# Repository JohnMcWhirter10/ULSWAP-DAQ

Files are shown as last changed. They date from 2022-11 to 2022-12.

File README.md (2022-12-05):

# Ultra Low Size Weight and Power Data Acquisition Unit C Project and Altium Files

The contents of this repository include the altium files for each subsystem in
appropriately named directories. The use of this repository is solely for Texas A&M 
University and Sandia National Laboratories.

## Authors

- John McWhirter
- Andrew Bainbridge
- Robert Brown

## Table of Contents

- Power Module Subsystem Altium Files
- Signal Conditioning Subsystem Altium Files
- Processor and Interface Altium Files
- Initial C Project for the PIC32 (Recommendation: Open in MPLAB X IDE)

## Documentation

The Documentation for the C Project can be found by following this path:

UL-SWaP-DaQ-1.0 > doxygen > html > index.html

To open in the browser, one must download the UL-SWaP-DaQ-1.0 Directory to 
their local machine and follow the path above to the index.html file.

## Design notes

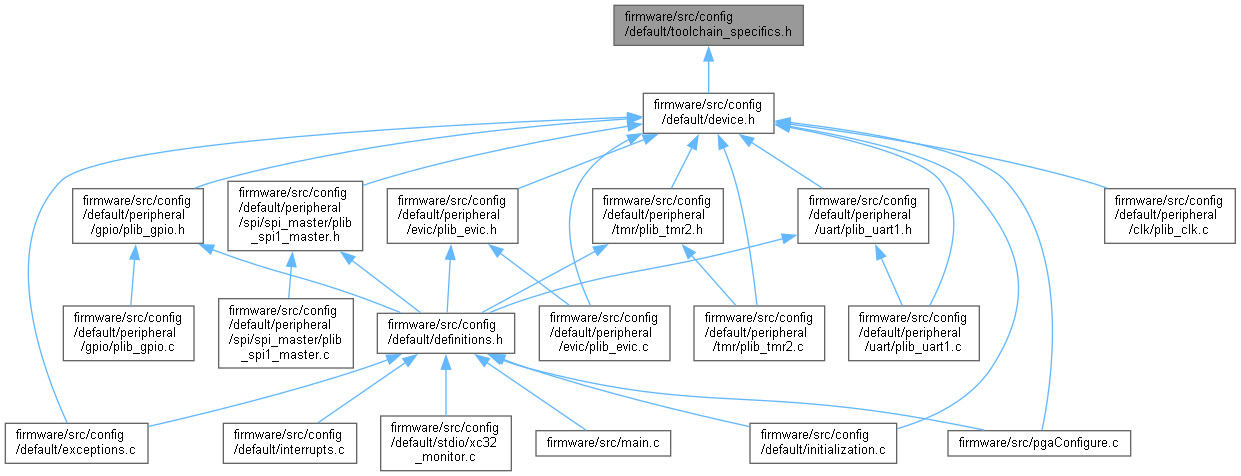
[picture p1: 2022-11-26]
ULSWAP-DAQ-1.0/doxygen/html/toolchain__specifics_8h__dep__incl.png

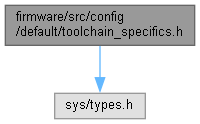
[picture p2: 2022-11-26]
ULSWAP-DAQ-1.0/doxygen/html/toolchain__specifics_8h__incl.png

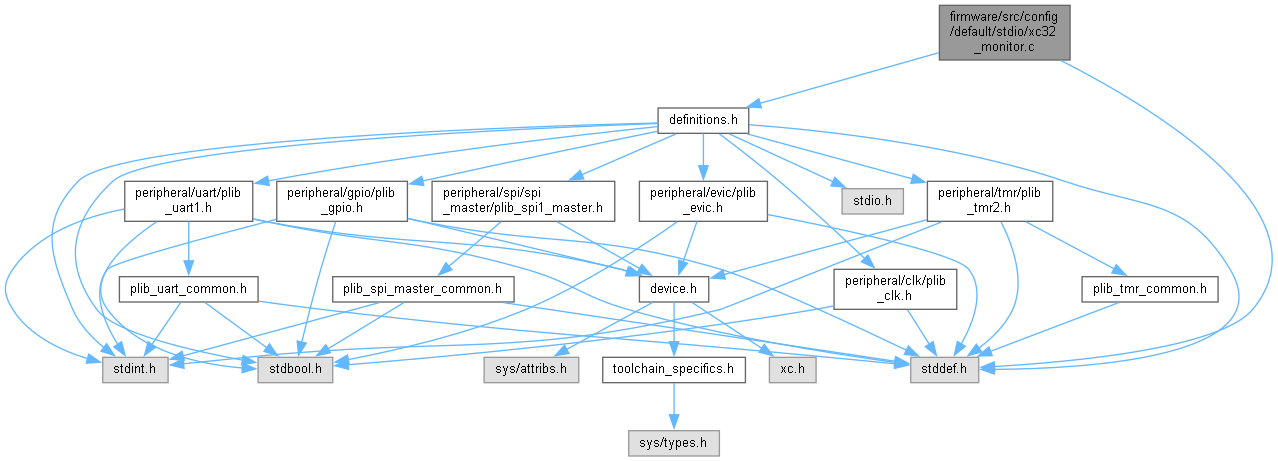
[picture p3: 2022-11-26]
ULSWAP-DAQ-1.0/doxygen/html/xc32__monitor_8c__incl.png

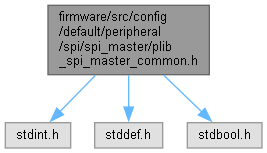
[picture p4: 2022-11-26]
ULSWAP-DAQ-1.0/doxygen/html/plib__spi__master__common_8h__incl.png

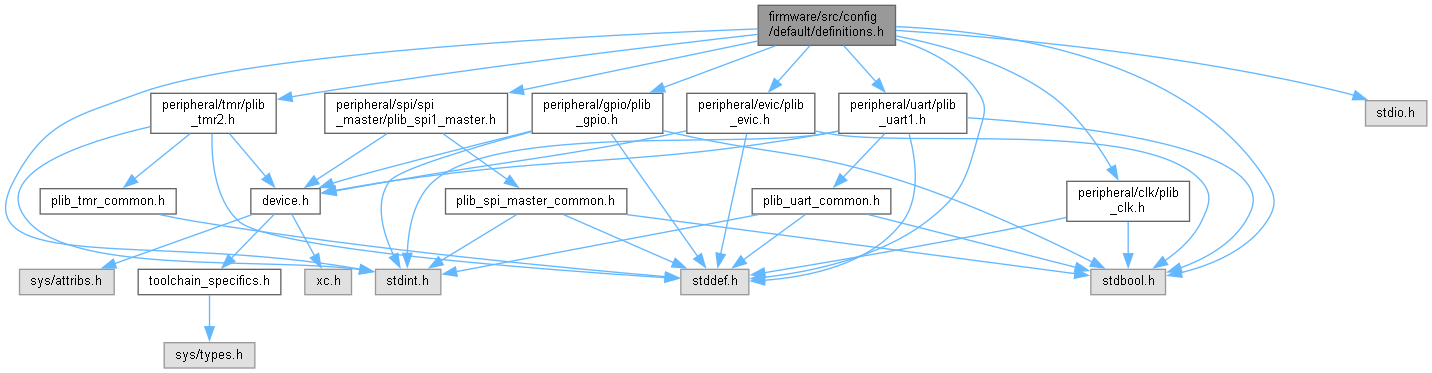
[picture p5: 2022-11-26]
ULSWAP-DAQ-1.0/doxygen/html/definitions_8h__incl.png

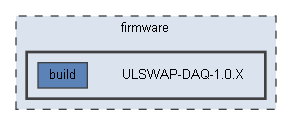
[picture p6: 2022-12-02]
ULSWAP-DAQ-1.0/doxygen/html/dir_9889642713a72f8b6f39e76810b143b5_dep.png

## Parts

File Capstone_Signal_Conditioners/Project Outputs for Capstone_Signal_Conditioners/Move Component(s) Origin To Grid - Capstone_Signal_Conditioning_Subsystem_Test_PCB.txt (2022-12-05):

Move Component(s) Origin to Grid
Filename     : C:\Users\Public\Documents\Altium\Capstone_Signal_Conditioners\Capstone_Signal_Conditioning_Subsystem_Test_PCB.PcbDoc
Date         : 11/2/2022
Time         : 10:20:12 AM
Time Elapsed : 00:00:00

    SOIC Component Designator6-Comment (40.64mm,61.849mm) on Top Layer - Component origin is already ON grid. - Component pads are OFF grid. No action taken.
    SOIC Component Designator5-Comment (40.95mm,68.893mm) on Top Layer - Component pads are OFF grid. No action taken.
    Component Designator2-Comment (25.656mm,65.752mm) on Top Layer - Component pads are OFF grid. No action taken.
count : 3

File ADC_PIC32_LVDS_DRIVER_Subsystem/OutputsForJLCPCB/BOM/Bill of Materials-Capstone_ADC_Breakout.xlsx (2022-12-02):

Comment | Designator | Footprint
C0805C476M9PACTU | C1 | FP-C0805C476M9PACTU-MFG
GRM155R71C104KA88D | C2, C3 | FP-GRM15-MFG
GRM188R71A225KE15D | C4 | FP-GRM188-0_1-e0_2_0_5-MFG
GRM188R60J106ME47D | C5 | FP-GRM188-0_1-e0_2_0_55-IPC_A
SSQ-108-01-T-S | J1, J2 | SMTC-SSQ-108-01-X-S
LTC2373CUH-16#PBF | U1 | LTC_2373_Footprint

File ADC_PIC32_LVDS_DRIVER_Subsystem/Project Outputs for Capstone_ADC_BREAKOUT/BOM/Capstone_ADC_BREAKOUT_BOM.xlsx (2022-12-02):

Designator | Description | Quantity | Comment | Footprint | LibRef
C1 | CAP CER 47UF 6.3V X5R 0805 | 1 | C0805C476M9PACTU | FP-C0805C476M9PACTU-MFG | CMP-2007-01008-2
C2, C3 | CAP CER 0.1UF 16V X7R 0402 | 2 | GRM155R71C104KA88D | FP-GRM15-MFG | CMP-2100-03641-2
C4 | Chip Multilayer Ceramic Capacitors for General Purpose, 0603, 2.2uF, X7R, 15%, 10%, 10V | 1 | GRM188R71A225KE15D | FP-GRM188-0_1-e0_2_0_5-MFG | CMP-2006-02836-2
C5 | Chip Multilayer Ceramic Capacitors for General Purpose, 0603, 10uF, X5R, 15%, 20%, 6.3V | 1 | GRM188R60J106ME47D | FP-GRM188-0_1-e0_2_0_55-IPC_A | CMP-2006-02792-2
J1, J2 | SQ Post Socket, Through-hole, Vertical, -55 to 105 degC, 2.54 mm Pitch, 8-Pin, Female, RoHS | 2 | SSQ-108-01-T-S | SMTC-SSQ-108-01-X-S | CMP-1023-00293-1
U1 |  | 1 | LTC2373CUH-16#PBF | LTC_2373_Footprint | LTC2373CUH-16#PBF

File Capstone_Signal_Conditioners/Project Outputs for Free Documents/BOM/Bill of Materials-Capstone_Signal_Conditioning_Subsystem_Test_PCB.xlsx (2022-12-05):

Comment | Designator | Footprint
LTC6362HMS8#PBF | AmpA, AmpB | LT-MS8-8_L
4-644456-0 | B1 | FP-4-644456-0-MFG
GRM3195C1H163JA01D | C1, C2 | FP-GRM319-0_15-IPC_A
CBR04C108B5GAC | C1A, C1B | FP-CBR04C-MFG
CC0603KRX7R9BB392 | C2A, C2B, C3A, C3B, C4A, C4B | FP-CC0603-DA-MFG
GRM155R71C104KA88D | Cp1-, Cp1+, Cp3-, Cp3+ | FP-GRM15-MFG
C2012JB1A685K060AC | Cp2-, Cp2+, Cp4-, Cp4+ | FP-C2012-060-0_2-IPC_A
NPTC102KFMS-RC | J1, J2 | FP-NPTC102KFMS-RC-0
THS7002CPWP | PGA1 | PWP0028E_M
AC0402JR-0750RL | R1, R2 | FP-AC0402-IPC_C
ERJ-6ENF1241V | R1A, R1B, RgA, RgB | RESC2013X70X40LL20T20
RC0805FR-071KL | R2A, R2B, RfA, RfB | RESC2013X60X35ML10T20
RC0402FR-0735R7L | RoA-, RoA+, RoB-, RoB+ | RESC1005X40X25ML05T10

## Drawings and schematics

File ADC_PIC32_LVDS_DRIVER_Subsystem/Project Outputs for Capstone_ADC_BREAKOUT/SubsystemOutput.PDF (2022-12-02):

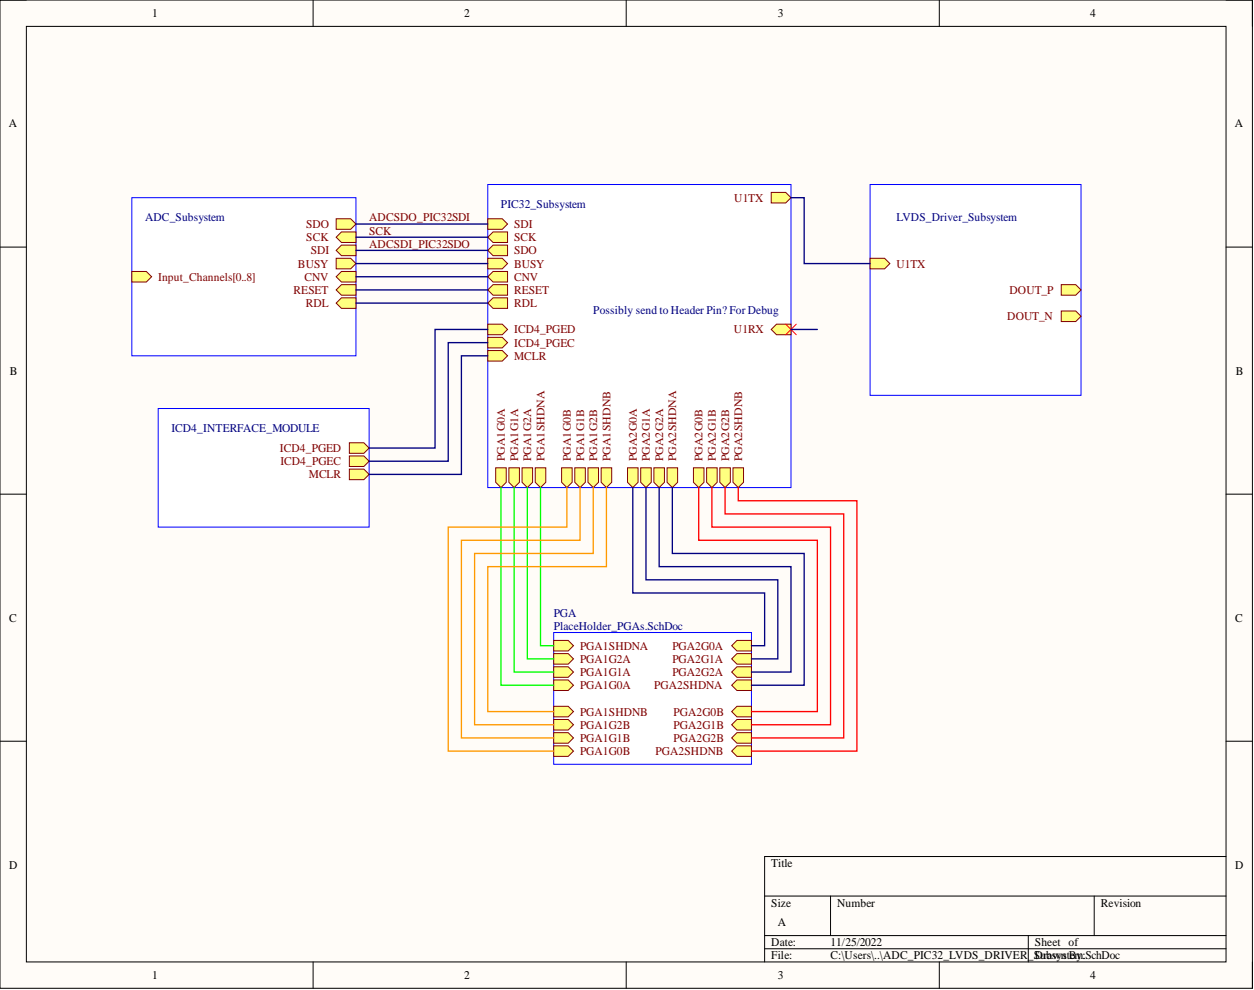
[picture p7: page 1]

Possibly send to Header Pin? For Debug

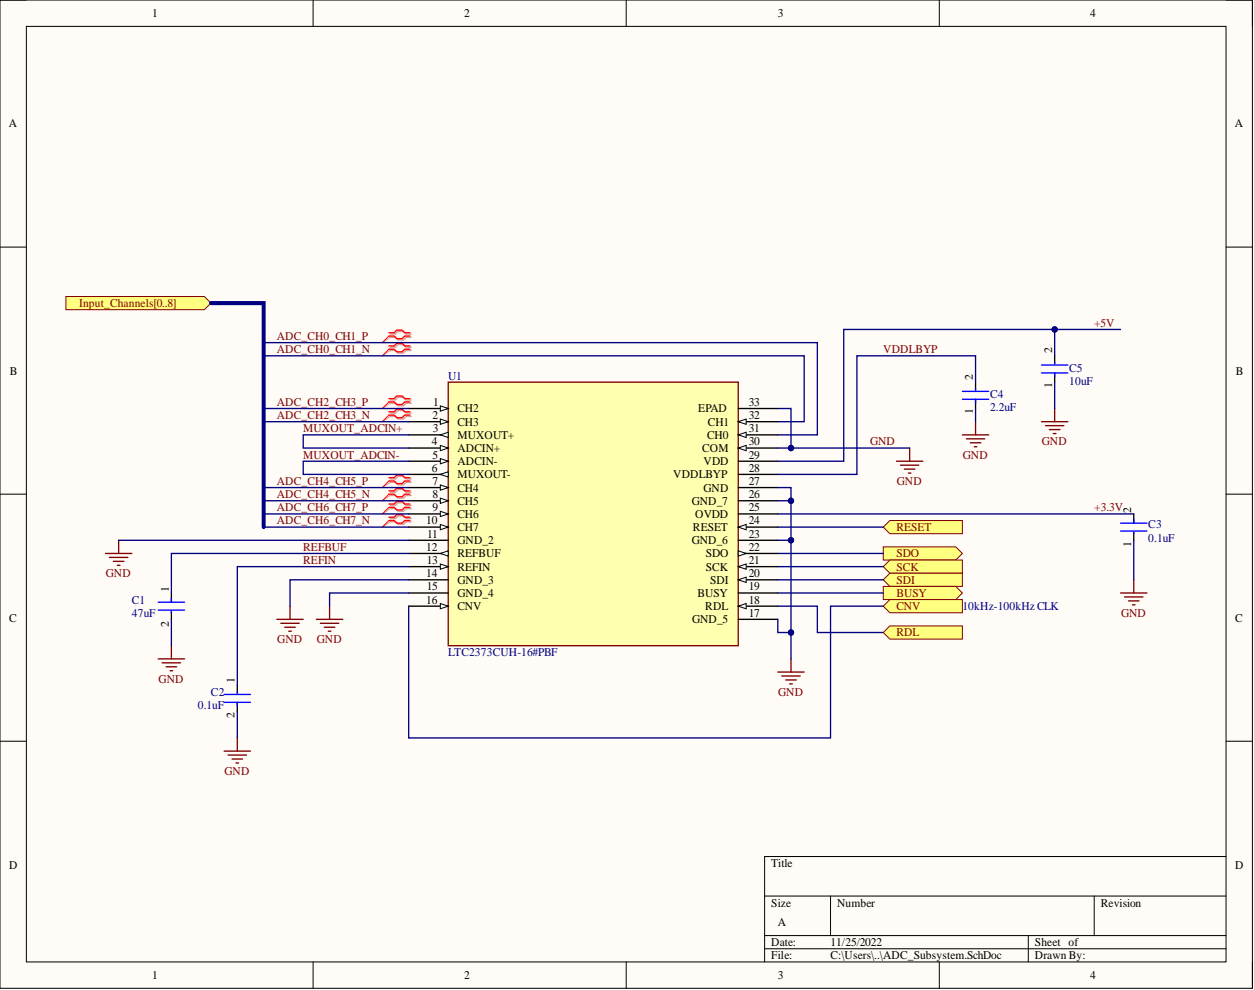
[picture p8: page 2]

MU X O U T _ A D C IN + 3 | CH MU X O U T + 0 | 3 1
A | | | A DCIN + M A DCIN -V D D MU X O U T-V D D LBY P CH 4 G N D CH 5 G N D _ 7 CH 6 O V D D RESE CH 7 T G N D _ 2 G N D _ 6 REFBU F O SCK REFI N SD G N D _ 3 I BU G N D _4 S Y CN V L | 3 0

A DC_CH 4 _ C H 5 _N 8 | | 2 6
A DC_CH 6 _ C H 7 _P 9 | | 2 5
A DC_CH 6 _ C H 7 _N 1 0 | | 2 4

REFBU F 1 | | 2 2
REFI N | 1 3 | | 2 1

1 4 | | 2 0
1 5 | | 1 9

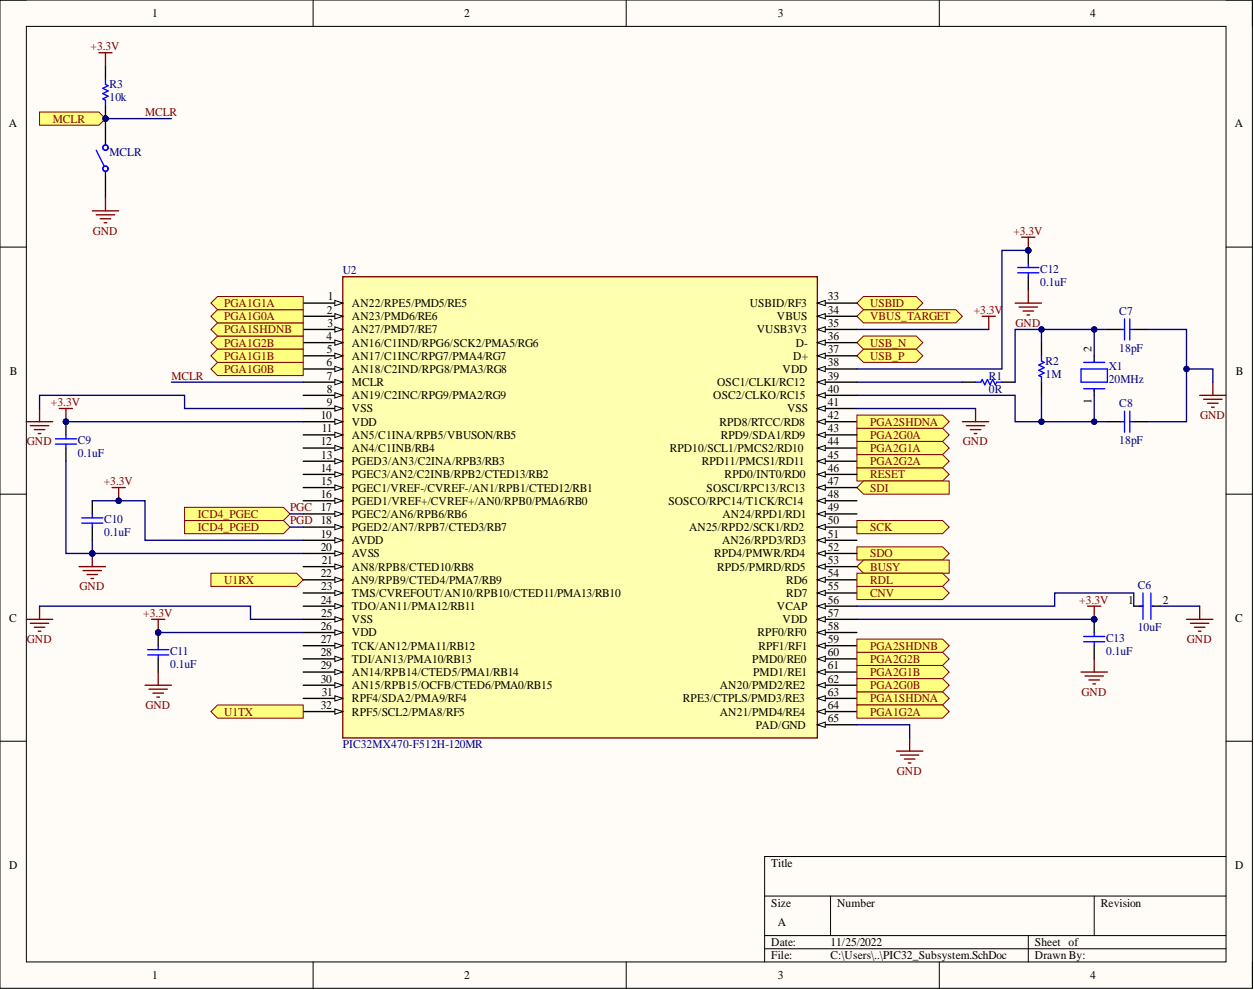
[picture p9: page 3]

1 0 | 4 2
1 1 | 4 3

5 6 | CN V +3.3 V 1
5 7

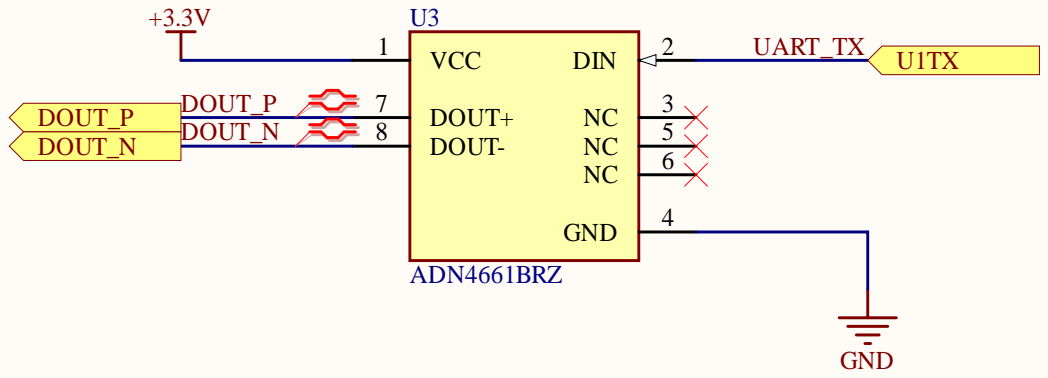
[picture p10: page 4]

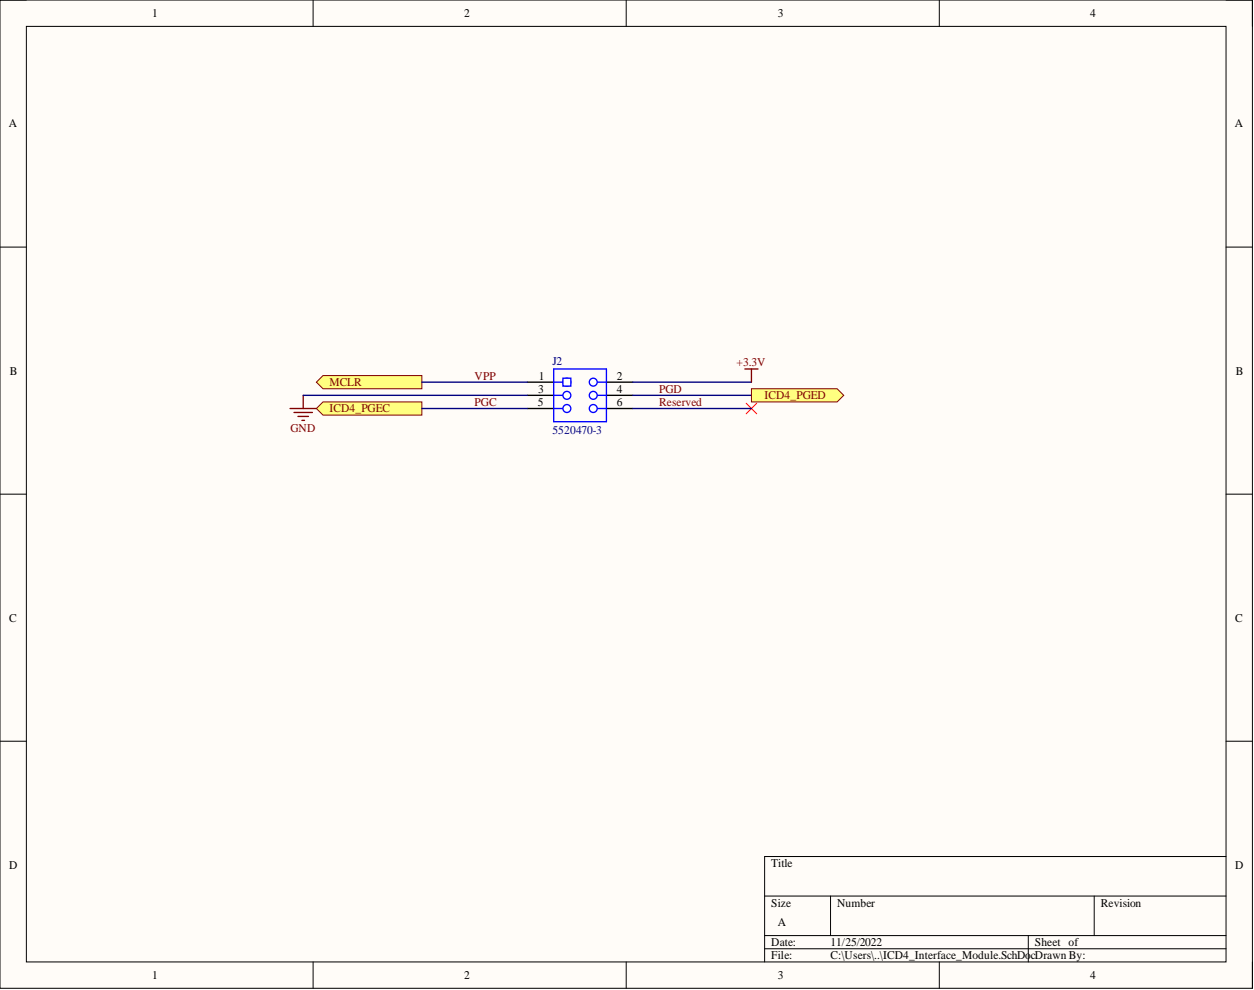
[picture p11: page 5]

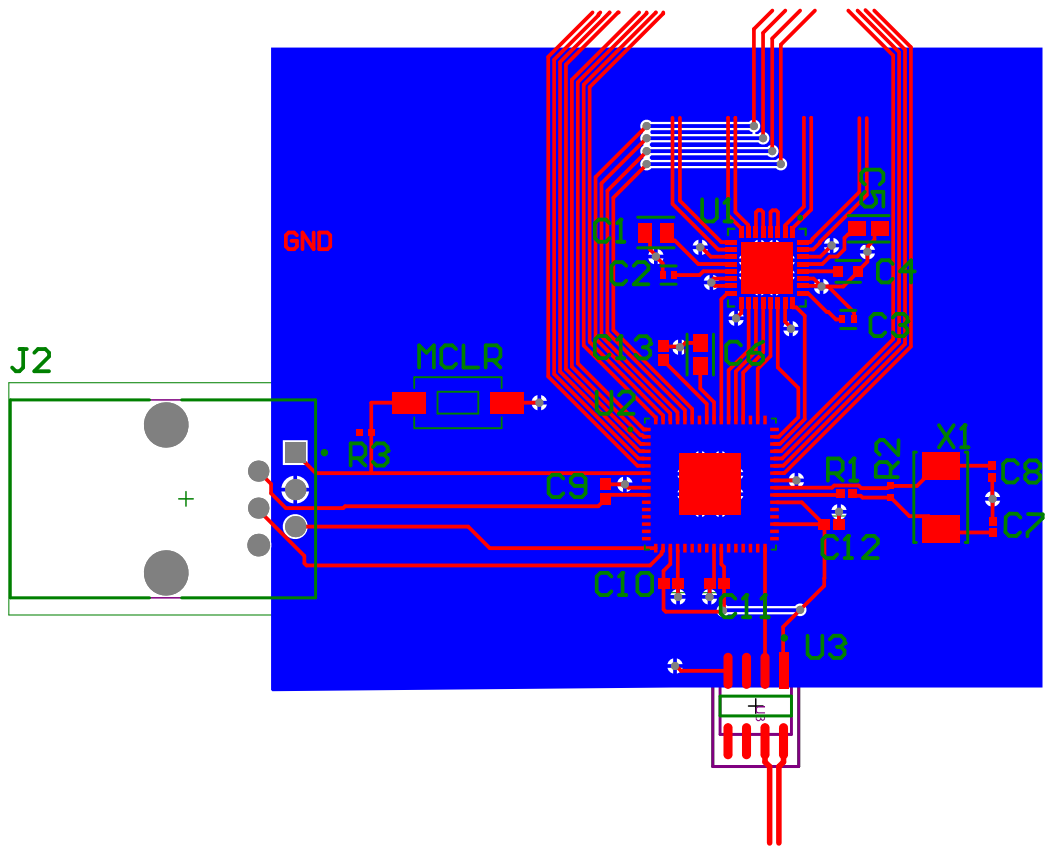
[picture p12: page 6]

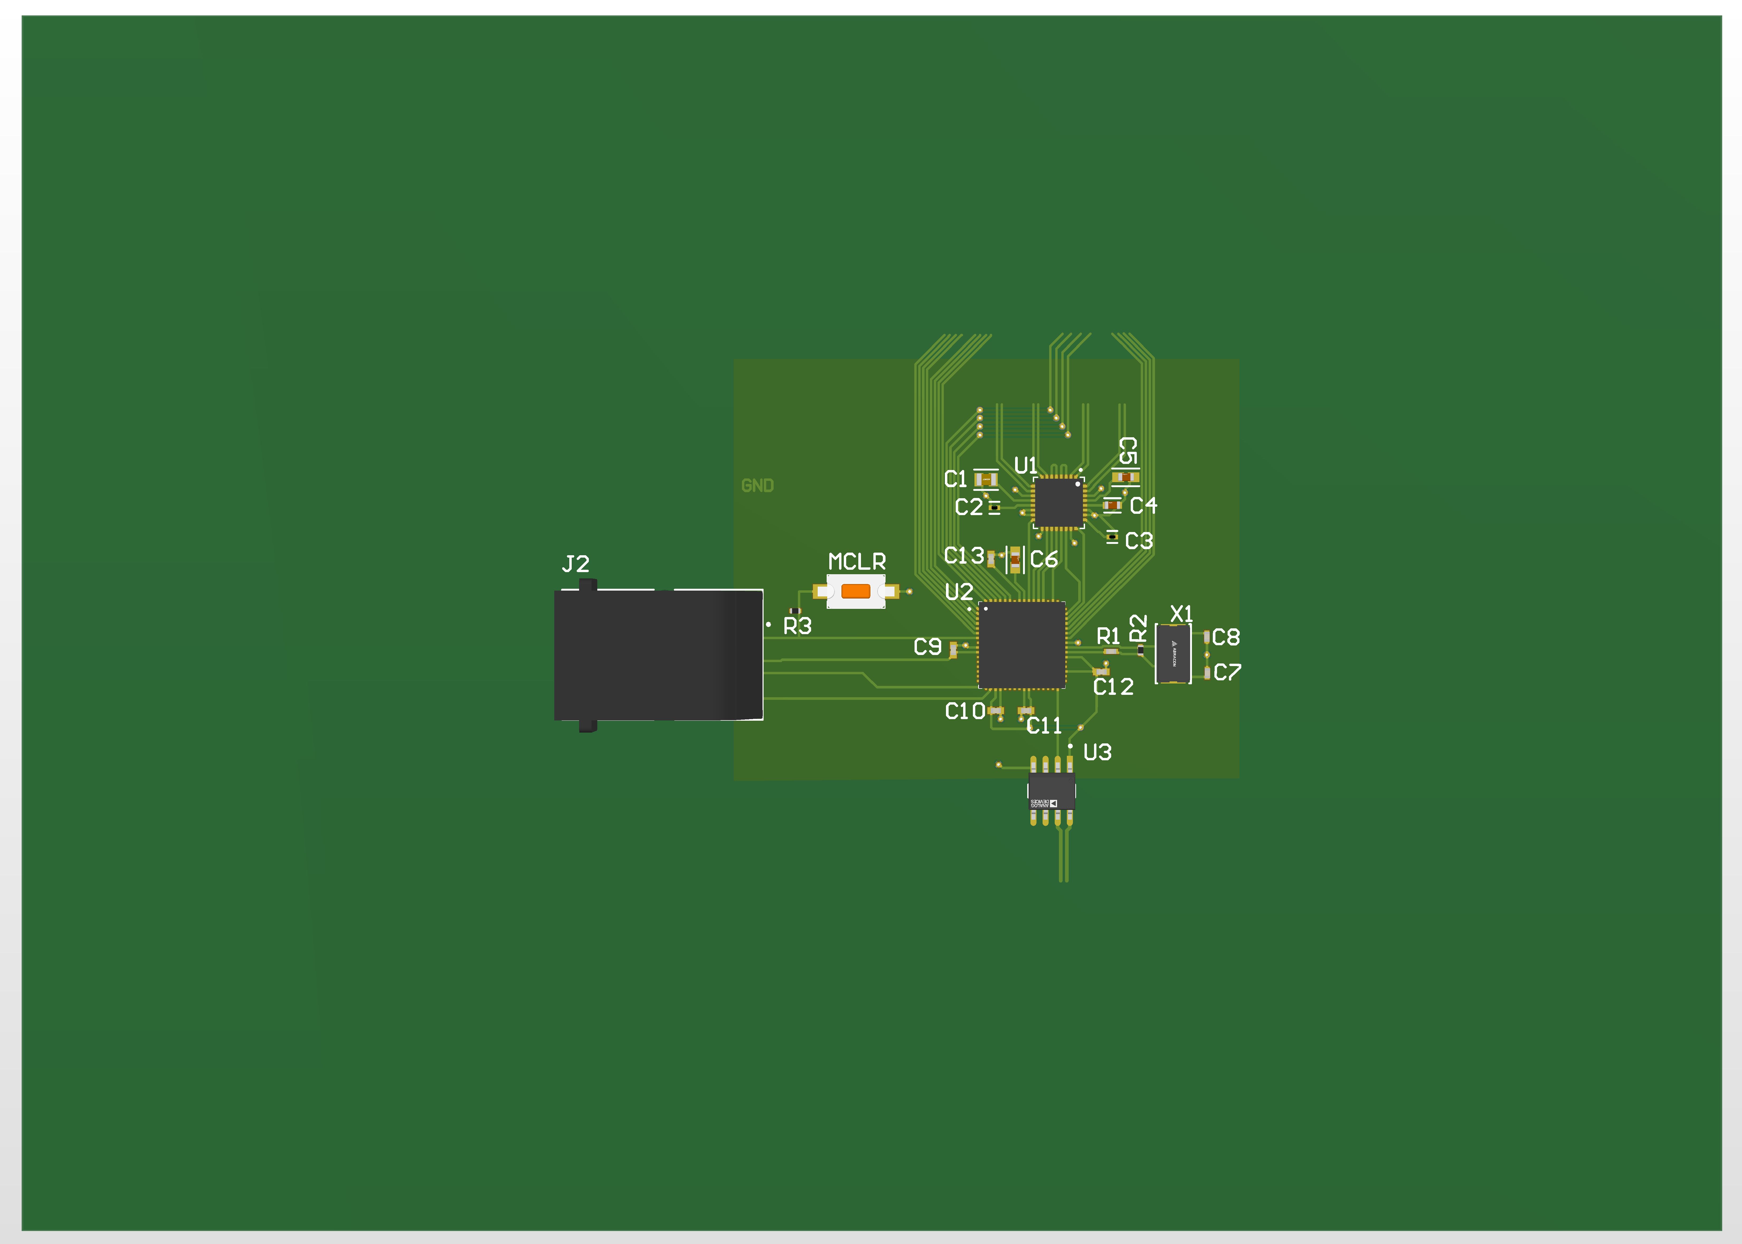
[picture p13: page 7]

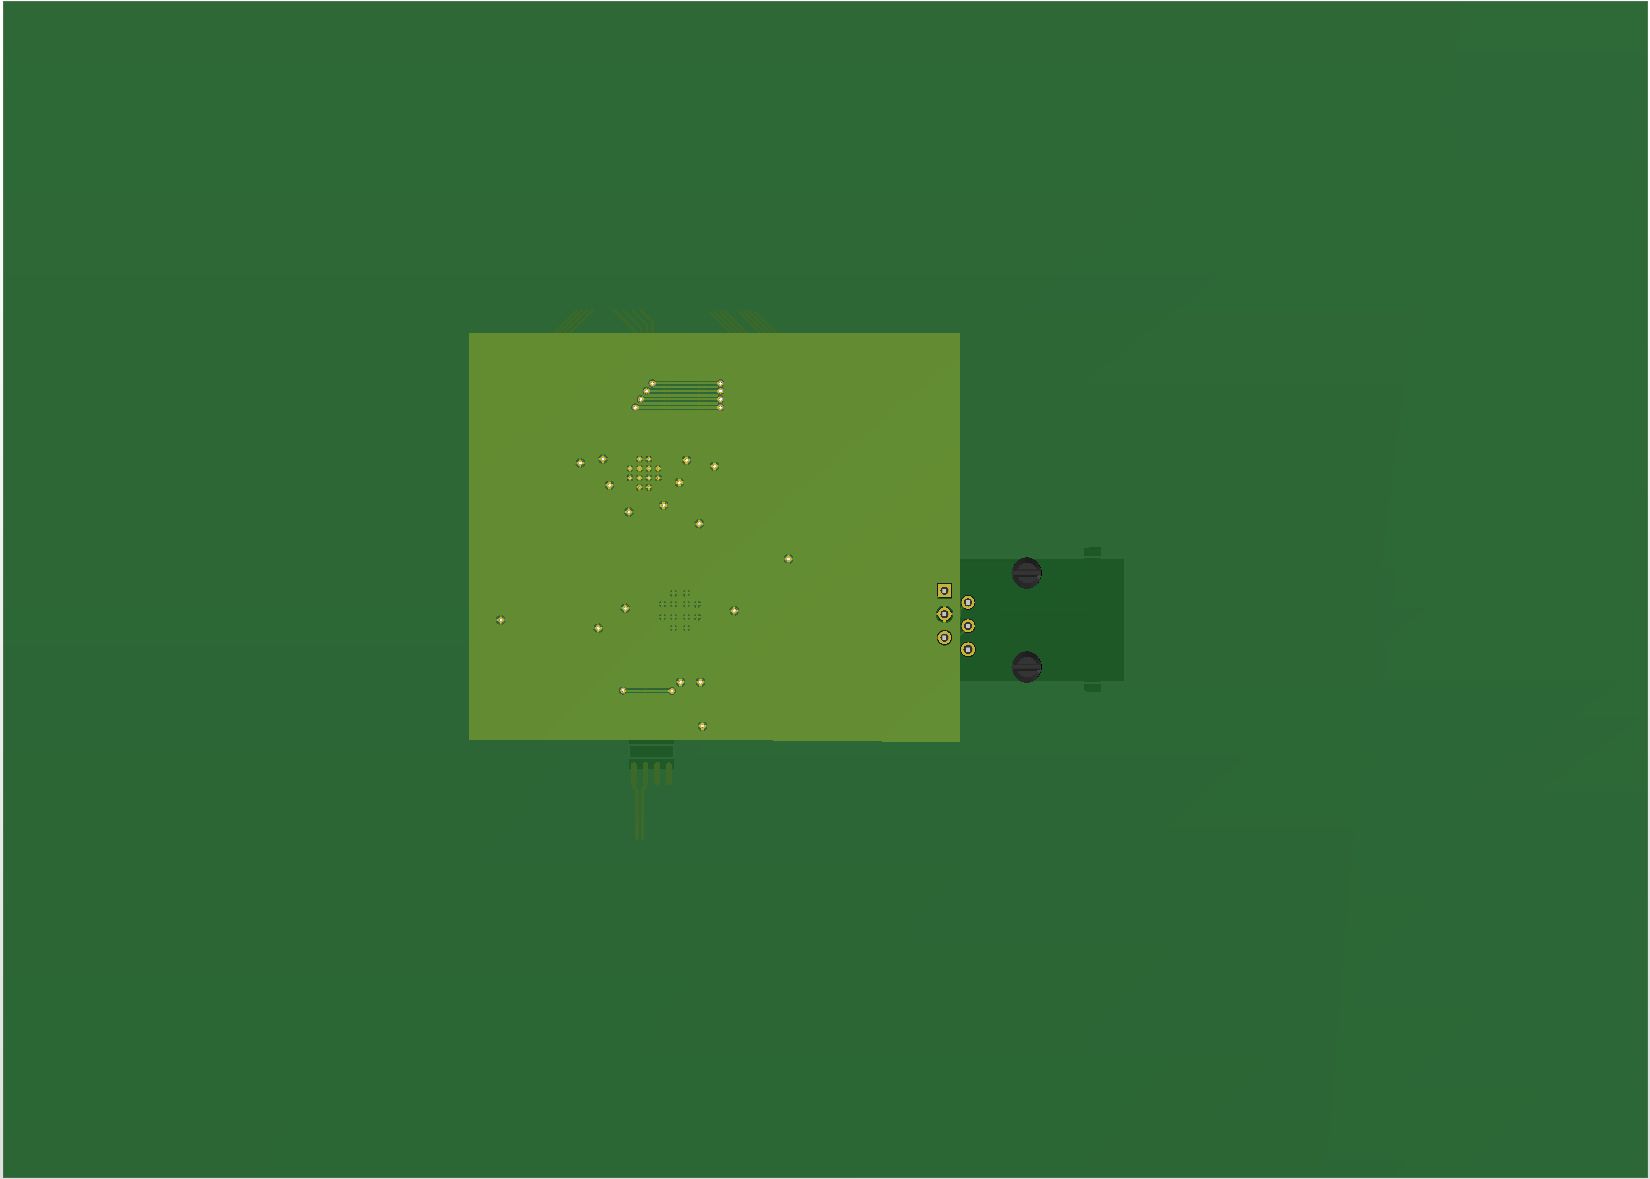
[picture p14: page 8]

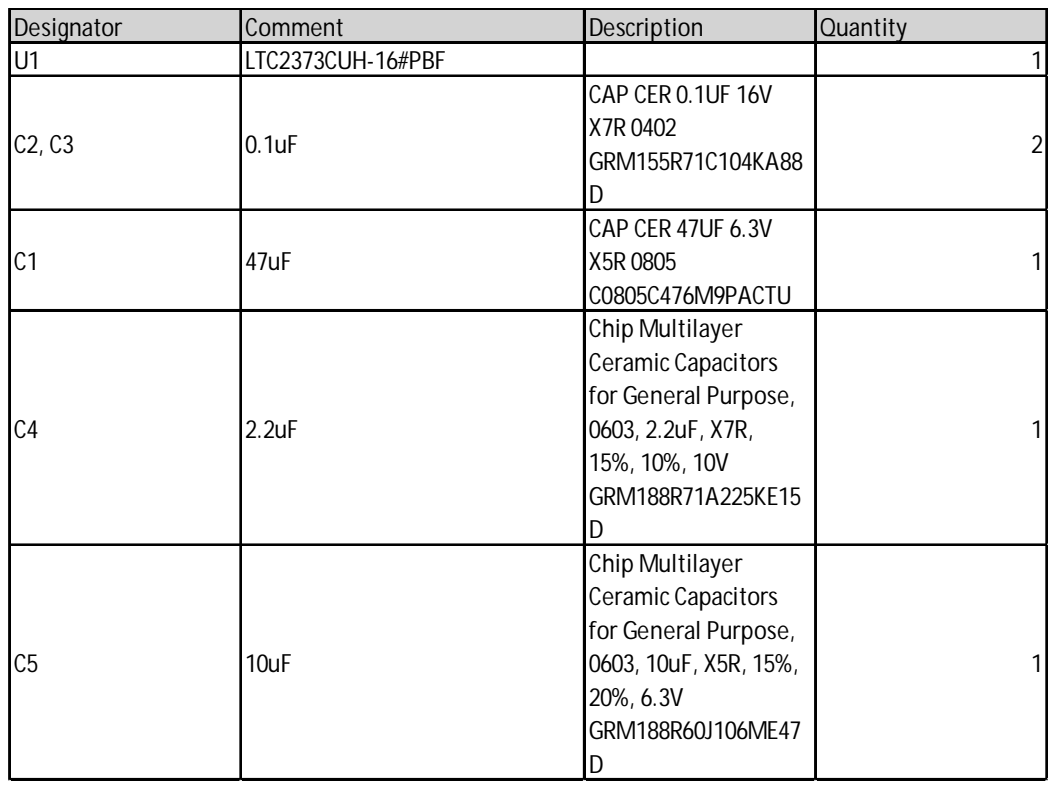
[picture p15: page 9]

Designator | Comment | Description | Quantity
U1 | LTC2373CUH-16#PBF | | 1
C2, C3 | 0.1uF | CAP CER 0.1UF 16V X7R 0402 GRM155R71C104KA88 D | 2

C1 | 47uF | CAP CER 47UF 6.3V X5R 0805 C0805C476M9PACTU | 1

C4 | 2.2uF | Chip Multilayer Ceramic Capacitors for General Purpose, 0603, 2.2uF, X7R, 15%, 10%, 10V GRM188R71A225KE15 D | 1

C5 | 10uF | Chip Multilayer Ceramic Capacitors for General Purpose, 0603, 10uF, X5R, 15%, 20%, 6.3V GRM188R60J106ME47 D | 1

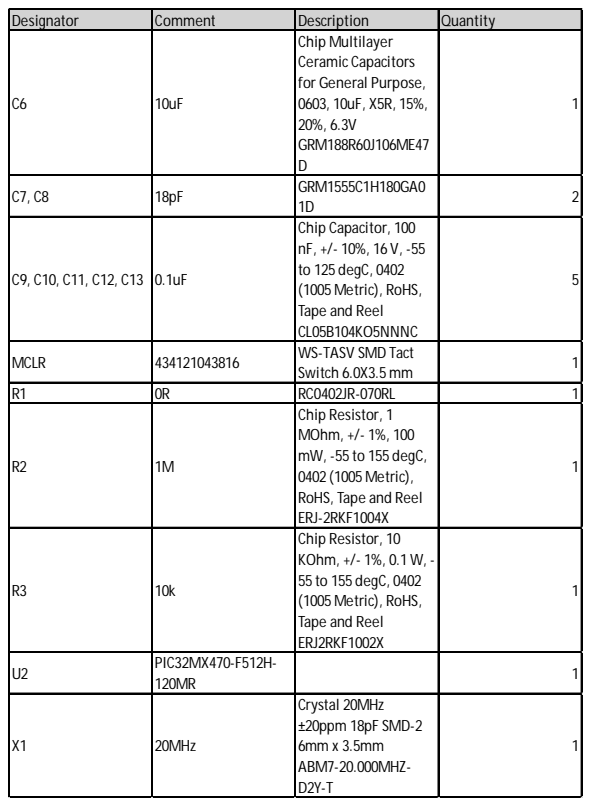
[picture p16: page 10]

Designator | Comment | Description | Quantity
C6 | 10uF | Chip Multilayer Ceramic Capacitors for General Purpose, 0603, 10uF, X5R, 15%, 20%, 6.3V GRM188R60J106ME47 D | 1

C7, C8 | 18pF | GRM1555C1H180GA0 1D | 2

C9, C10, C11, C12, C13 | 0.1uF | Chip Capacitor, 100 nF, +/- 10%, 16 V, -55 to 125 degC, 0402 (1005 Metric), RoHS, Tape and Reel CL05B104KO5NNNC | 5

MCLR | 434121043816 | WS-TASV SMD Tact Switch 6.0X3.5mm | 1

R1 | 0R | RC0402JR-070RL | 1
R2 | 1M | Chip Resistor, 1 MOhm, +/- 1%, 100 mW, -55 to 155 degC, 0402 (1005 Metric), RoHS, Tape and Reel ERJ-2RKF1004X | 1

R3 | 10k | Chip Resistor, 10 KOhm, +/- 1%, 0.1 W, -55 to 155 degC, 0402 (1005 Metric), RoHS, Tape and Reel ERJ2RKF1002X | 1

U2 | PIC32MX470-F512H-120MR | | 1

X1 | 20MHz | Crystal 20MHz ±20ppm 18pF SMD-2 6mm x 3.5mm ABM7-20.000MHZ-D2Y-T | 1

Designator | Comment | Description | Quantity
U3 | ADN4661BRZ | IC DRIVER 1/0 8SOIC | 1

Designator | Description | Comment | Quantity
J2 | Modular Jack, 6 Position, Right Angle, RoHS, Tray | 5520470-3 | 1

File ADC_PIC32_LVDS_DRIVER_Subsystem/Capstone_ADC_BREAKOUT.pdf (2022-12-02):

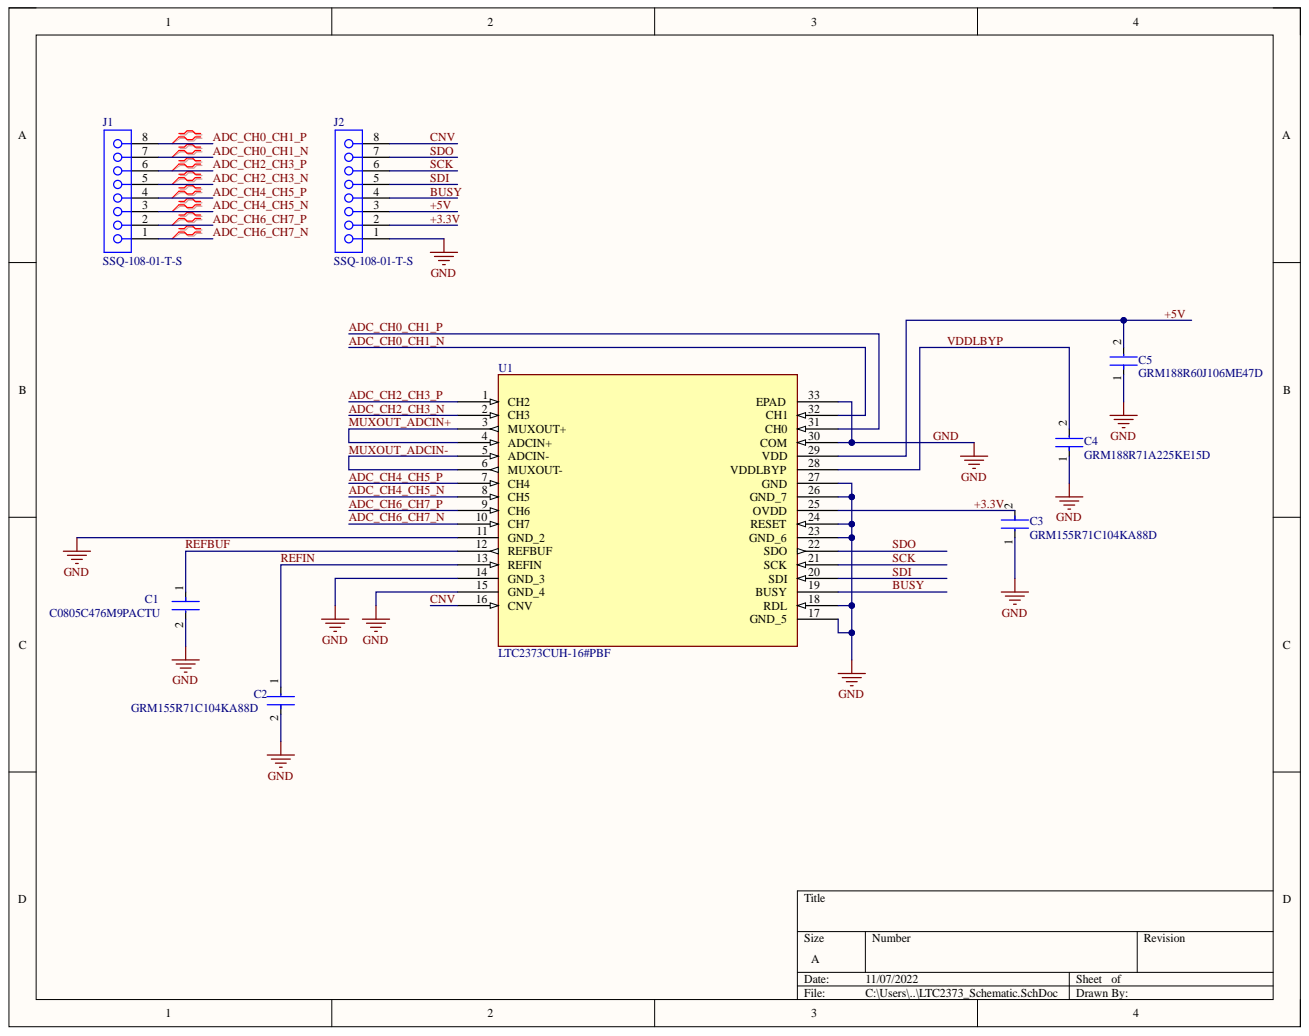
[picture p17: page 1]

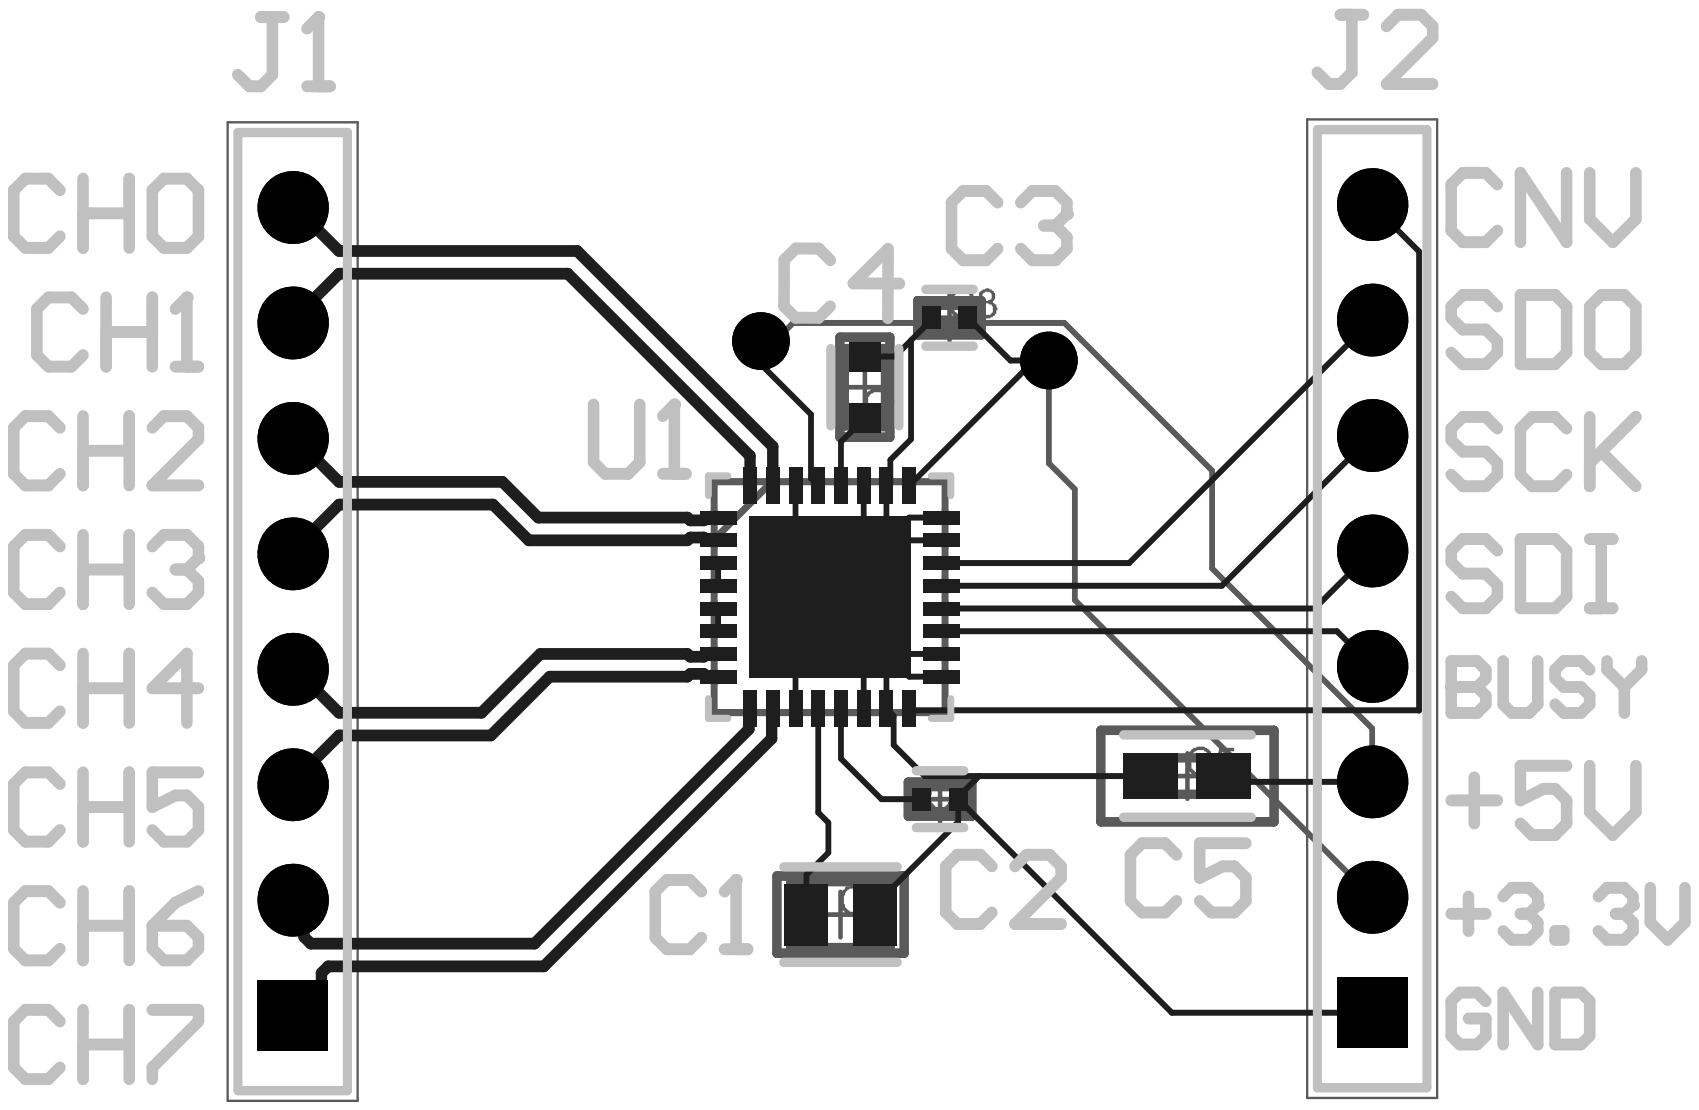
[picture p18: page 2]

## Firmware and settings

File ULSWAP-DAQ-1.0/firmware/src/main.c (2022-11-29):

/* ============================================================================*/
/**
 * @file main.c
 * @author John McWhirter
 * @date 11/2022
 * @brief main file for Data Acquisition Unit
 * 
*/
/* ============================================================================*/
/*! \mainpage Ultra Low Size Weight and Power Data Acquisition
 * 
 * \section Introduction
 * The following page will be a useful guide in navigating the comments and code
 *  of this project. The main function of the PIC32 programmed with this code is 
 *  to adjust the gains of each of the PGAs, Read and Write SPI messages to the 
 *  LTC2373 for data acquisition, and output the message onto UART. 
 * 
 * \section Gain Configuration Table
 * | config #| Gain dB | Gain V/V |
 * |---------|---------|----------|
 * |   0     |   -22   |   0.08   |
 * |   1     |   -16   |   0.16   |
 * |   2     |   -10   |   0.32   |
 * |   3     |    -4   |   0.63   |
 * |   4     |     2   |   1.26   |
 * |   5     |     8   |   2.52   |
 * |   6     |    14   |   5.01   |
 * |   7     |    20   |   10.0   |
 *   
 * \section Navigation
 * The Table of Contents to the Left will be the main tool for guiding through
 * this documentation. Notice the Files tab. The main.c file can be found in
 * Files > File List > firmware > src. In addition, here you will find most of 
 * the code I have written. In the config folder, you will find the MPLAB X IDE
 * Harmony v3 generated Modules for SPI, UART, GPIO, etc. 
*/
// *****************************************************************************
// *****************************************************************************
// Section: Included Files
// *****************************************************************************
// *****************************************************************************

#include <stddef.h>                     // Defines NULL
#include <stdbool.h>                    // Defines true
#include <stdlib.h>                     // Defines EXIT_FAILURE
#include "definitions.h"                // SYS function prototypes
#include <string.h>
#include <pgaConfigure.h>


// *****************************************************************************
// *****************************************************************************
// Section: Main Entry Point
// *****************************************************************************
// *****************************************************************************

/**
 * These are defined to shutdown PGAs in use
 * True for Shutdown, False for On
 */
uint8_t pga1A_shdn = 0;
uint8_t pga1B_shdn = 0;
uint8_t pga2A_shdn = 0;
uint8_t pga2B_shdn = 0;


/*! 
 */

/**
 * PGA Configuration Members
 */
uint8_t pga1A_config = 0;
uint8_t pga1B_config = 0;
uint8_t pga2A_config = 0;
uint8_t pga2B_config = 0;

/**
 * Configuration word is used to switch the mux within the ADC
 * The word will work as our "State" machine
 * Note: It is not what is sent to the ADC. It is 4 bits in the word that will
 * be sent.
 */
uint8_t config = 0;
uint8_t reset_word = 0;
bool next = false;

void check_TMR2(uint32_t status, uintptr_t context){
    next = true;
}

/**
 * main
 * @return 
 */
int main ( void )
{
    /* Initialize all modules */
    SYS_Initialize ( NULL );
    
    /* Initialize TMR2 Callback Register for 10kHz Frequency*/
    TMR2_CallbackRegister(check_TMR2, (uintptr_t) NULL);
    
    /* Configure PGAs refer to PGA datasheet for combinations */
    configurePGA1A(pga1A_config, pga1A_shdn);
    configurePGA1B(pga1B_config, pga1B_shdn);
    configurePGA2A(pga2A_config, pga2A_shdn);
    configurePGA2B(pga2B_config, pga2B_shdn);
    
    /* Reset ADC */
    RESET_Set();
    RESET_Clear();
    RDL_Set();
    CNV_Set();
    for(int i = 0; i < 1000; i++);
    CNV_Clear();
    while(BUSY_Get());
    RDL_Clear();
    SPI1_Write(&reset_word, 1);
    while(SPI1_IsBusy());

    /* Program Sequencer */

    for( uint8_t i = 0; i < 15; i++){
        // configuration word is config left shifted by 3 bits plus
        //  the input range selection bits (10) and Digital Gain Compression (0)
        uint8_t config_word = (i << 3) + 4; // 0x0AAAA100 where A is config
        RDL_Set();
        CNV_Set();
        CNV_Clear();
        while(BUSY_Get());
        RDL_Clear();
        SPI1_Write(&config_word, 1);
        while(SPI1_IsBusy());
    }
    
    /* Read From ADC*/
    while ( true )
    {
        /**
         * If statements will skip Mux channels if they are not populated
         * Note: If we are on this state and this state's PGA is shutdown, skip
         */
        if(pga1A_shdn && config == 0){ 
            config = config + 1; 
        } 
        if(pga1B_shdn && config == 1){
            config = config + 1;
        }
        if(pga2A_shdn && config == 2){
            config = config + 1;
        }
        if(pga2B_shdn && config == 3){
            config = 0;
        }
        // configuration word is config left shifted by 3 bits plus
        //  the input range selection bits (10) and Digital Gain Compression (0)
        //uint8_t config_word = (config << 3) + 4; // 0x0AAAA100 where A is config
        //RDL_Set();
        //CNV_Set();
        //CNV_Clear();
        //while(BUSY_Get());
        //RDL_Clear();
        //SPI1_Write(&config_word, 1);
        //while(SPI1_IsBusy());
        
        char miso_buff[3];
        RDL_Set();
        CNV_Set();
        CNV_Clear();
        while(BUSY_Get());
        RDL_Clear();
        SPI1_Read(&miso_buff, 3);
        while(SPI1_IsBusy());
        
        // Split Received Buffer into Data and Configuration word
        uint16_t rxdata = (miso_buff[2] << 8) + miso_buff[1];
        
        // Create float percentage of rxdata and multiply it by 
        //  Input Range from Data Sheet [-4.096, 4.096]
        float txdata = (rxdata / 65535.0) * 8.192 - 4.096;
        
        // Write Result onto UART1 
        char tx_buffer[50];
        sprintf(tx_buffer, "%0.2f", txdata);
        UART1_Write(&tx_buffer, strlen(tx_buffer));
        
        // Increment config
        config = config + 1; 
        while(!next);
        next = false;
        /* Maintain state machines of all polled MPLAB Harmony modules. */
        SYS_Tasks ( );
    }

    /* Execution should not come here during normal operation */

    return ( EXIT_FAILURE );
}


/*******************************************************************************
 End of File
*/

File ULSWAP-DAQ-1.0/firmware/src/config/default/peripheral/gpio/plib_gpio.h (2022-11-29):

/*******************************************************************************
  GPIO PLIB

  Company:
    Microchip Technology Inc.

  File Name:
    plib_gpio.h

  Summary:
    GPIO PLIB Header File

  Description:
    This library provides an interface to control and interact with Parallel
    Input/Output controller (GPIO) module.

*******************************************************************************/

/*******************************************************************************
* Copyright (C) 2019 Microchip Technology Inc. and its subsidiaries.
*
* Subject to your compliance with these terms, you may use Microchip software
* and any derivatives exclusively with Microchip products. It is your
* responsibility to comply with third party license terms applicable to your
* use of third party software (including open source software) that may
* accompany Microchip software.
*
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
* IN NO EVENT WILL MICROCHIP BE LIABLE FOR ANY INDIRECT, SPECIAL, PUNITIVE,
* INCIDENTAL OR CONSEQUENTIAL LOSS, DAMAGE, COST OR EXPENSE OF ANY KIND
* WHATSOEVER RELATED TO THE SOFTWARE, HOWEVER CAUSED, EVEN IF MICROCHIP HAS
* BEEN ADVISED OF THE POSSIBILITY OR THE DAMAGES ARE FORESEEABLE. TO THE
* FULLEST EXTENT ALLOWED BY LAW, MICROCHIP'S TOTAL LIABILITY ON ALL CLAIMS IN
* ANY WAY RELATED TO THIS SOFTWARE WILL NOT EXCEED THE AMOUNT OF FEES, IF ANY,
* THAT YOU HAVE PAID DIRECTLY TO MICROCHIP FOR THIS SOFTWARE.
*******************************************************************************/

#ifndef PLIB_GPIO_H
#define PLIB_GPIO_H

#include <device.h>
#include <stdint.h>
#include <stdbool.h>
#include <stddef.h>

// DOM-IGNORE-BEGIN
#ifdef __cplusplus  // Provide C++ Compatibility

    extern "C" {

#endif
// DOM-IGNORE-END

// *****************************************************************************
// *****************************************************************************
// Section: Data types and constants
// *****************************************************************************
// *****************************************************************************


/*** Macros for PGA1G1A pin ***/
#define PGA1G1A_Set()               (LATESET = (1<<5))
#define PGA1G1A_Clear()             (LATECLR = (1<<5))
#define PGA1G1A_Toggle()            (LATEINV= (1<<5))
#define PGA1G1A_OutputEnable()      (TRISECLR = (1<<5))
#define PGA1G1A_InputEnable()       (TRISESET = (1<<5))
#define PGA1G1A_Get()               ((PORTE >> 5) & 0x1)
#define PGA1G1A_PIN                  GPIO_PIN_RE5

/*** Macros for PGA1G0A pin ***/
#define PGA1G0A_Set()               (LATESET = (1<<6))
#define PGA1G0A_Clear()             (LATECLR = (1<<6))
#define PGA1G0A_Toggle()            (LATEINV= (1<<6))
#define PGA1G0A_OutputEnable()      (TRISECLR = (1<<6))
#define PGA1G0A_InputEnable()       (TRISESET = (1<<6))
#define PGA1G0A_Get()               ((PORTE >> 6) & 0x1)
#define PGA1G0A_PIN                  GPIO_PIN_RE6

/*** Macros for PGA1SHDNB pin ***/
#define PGA1SHDNB_Set()               (LATESET = (1<<7))
#define PGA1SHDNB_Clear()             (LATECLR = (1<<7))
#define PGA1SHDNB_Toggle()            (LATEINV= (1<<7))
#define PGA1SHDNB_OutputEnable()      (TRISECLR = (1<<7))
#define PGA1SHDNB_InputEnable()       (TRISESET = (1<<7))
#define PGA1SHDNB_Get()               ((PORTE >> 7) & 0x1)
#define PGA1SHDNB_PIN                  GPIO_PIN_RE7

/*** Macros for PGA1G2B pin ***/
#define PGA1G2B_Set()               (LATGSET = (1<<6))
#define PGA1G2B_Clear()             (LATGCLR = (1<<6))
#define PGA1G2B_Toggle()            (LATGINV= (1<<6))
#define PGA1G2B_OutputEnable()      (TRISGCLR = (1<<6))
#define PGA1G2B_InputEnable()       (TRISGSET = (1<<6))
#define PGA1G2B_Get()               ((PORTG >> 6) & 0x1)
#define PGA1G2B_PIN                  GPIO_PIN_RG6

/*** Macros for PGA1G1B pin ***/
#define PGA1G1B_Set()               (LATGSET = (1<<7))
#define PGA1G1B_Clear()             (LATGCLR = (1<<7))
#define PGA1G1B_Toggle()            (LATGINV= (1<<7))
#define PGA1G1B_OutputEnable()      (TRISGCLR = (1<<7))
#define PGA1G1B_InputEnable()       (TRISGSET = (1<<7))
#define PGA1G1B_Get()               ((PORTG >> 7) & 0x1)
#define PGA1G1B_PIN                  GPIO_PIN_RG7

/*** Macros for PGA1G0B pin ***/
#define PGA1G0B_Set()               (LATGSET = (1<<8))
#define PGA1G0B_Clear()             (LATGCLR = (1<<8))
#define PGA1G0B_Toggle()            (LATGINV= (1<<8))
#define PGA1G0B_OutputEnable()      (TRISGCLR = (1<<8))
#define PGA1G0B_InputEnable()       (TRISGSET = (1<<8))
#define PGA1G0B_Get()               ((PORTG >> 8) & 0x1)
#define PGA1G0B_PIN                  GPIO_PIN_RG8
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

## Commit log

2022-12-02 Adding Altium Files
    The Altium files in this commit contain two PCB designs: an ADC breakout Board and the Processor and interface Subsystem. To open in Altium, simply download the PCB_Project directory as a zip and ope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
    [ADC_PIC32_LVDS_DRIVER_Subsystem.PcbDoc, ADC_PIC32_LVDS_DRIVER_Subsystem.SchDoc, ADC_Subsystem.SchDoc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]
2022-12-02 Renaming the PCB_Project
    The PCB_Project folder has been renamed to better suit its contents. PCB designs, schematics, and libraries for the Processor and Interface Subsystem.
    [ADC_PIC32_LVDS_DRIVER_Subsystem.PcbDoc, ADC_PIC32_LVDS_DRIVER_Subsystem.SchDoc, ADC_Subsystem.SchDoc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]
2022-12-03 Extracted ZIP File
    [Bill of Materials-Capstone_Signal_Conditioning_Subsystem_Test_PCB.xlsx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]
2022-12-03 Project Output Folder of Signal Conditioner
    This is for my demo circuit, the final PCB is still being made
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2022-12-05 Signal Conditioning Docs
    PCB Documents for Signal Conditioning Subsystem
    [Bill of Materials-Capstone_Signal_Conditioning_Subsystem_Test_PCB.xlsx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]
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2022-12-05 Create Signal Conditioning PCB
    Signal Conditioning PCB files
2022-12-05 delete Signal Conditioning PCB
    PCB docs for signal conditioning
2022-12-05 Create Signal Conditioning PCB
    PCB Signal Conditioners
    [Bill of Materials-Capstone_Signal_Conditioning_Subsystem_Test_PCB.xlsx, Capstone_Signal_Conditioners.PrjPcb, Capstone_Signal_Conditioners_Final_Schematic.SchDo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]
2022-12-05 Adding Fully Integrated PCB to files. Beginning place and routing of Processor and Interface Subsystem.
    [ADC_PIC32_LVDS_DRIVER_Subsystem.SchDoc, PlaceHolder_PGAs.SchDoc]
2022-12-05 Correcting File Hiearchy and adding correct schematic and PCB documents to UL-SWAP
    [403mainschematic.SchDoc, ADC_Subsystem.SchDoc, Capstone_Signal_Conditioners_Final_Schematic.SchDoc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]
2022-12-05 Create Capstone_Signal_Conditioning_Subsystem_Test_PCB.PcbDoc
    Updated PCB for Signal Conditioners and Added Documents Folder
    [Capstone_Signal_Conditioning_Subsystem_Test_PCB.PcbDoc]
2022-12-05 Updated Schematic Capacitor Comments
    Changed the capacitors comments to be more fluid. Each Capacitor and resistor should have a consistent format.
    [Bill of Materials-Capstone_Signal_Conditioning_Subsystem_Test_PCB.xlsx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]
2022-12-06 Testing modified schematics
    [Capstone_Signal_Conditioning_Subsystem_Test_PCB.PcbDoc, LTC6362_Schematic.SchDoc, UL-SWAP-DAQ-1.PrjPcb]
2022-12-06 Updated Final PCB and Schematic and added Signal Conditioners to PCB
    [Capstone_Signal_Conditioners_Subsystem_Test_Schematic.SchDoc, Capstone_Signal_Conditioning_Subsystem_Test_PCB.PcbDoc, LTC6362_Schematic.SchDoc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]
2022-12-06 Updating Github with work done by Andrew on December 5th. PGA resistors and capacitors renamed to be consistent with PCB designs. Critical path of circuit current being developed.
2022-12-06 Updating Differential Routes. Updating Schematic ports to easily assign nets.
    [ADC_PIC32_LVDS_DRIVER_Subsystem.SchDoc, ADC_Subsystem.SchDoc, Capstone_Signal_Conditioners_Subsystem_Test_Schematic.SchDoc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]
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2022-12-06 Adding routes to GPIO pins between PIC32 and each PGA. Changing some of the route names for better connections.
    [403mainschematic.SchDoc, ADC_PIC32_LVDS_DRIVER_Subsystem.SchDoc, Capstone_Signal_Conditioners_Subsystem_Test_Schematic.SchDoc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]
2022-12-07 Testing github on Altium from my PC
    [PIC32_Subsystem.SchDoc]
2022-12-07 Edited Resistor and Capacitor Values for PGA 1
    [THS7002CPWP_Schematic.SchDoc]
2022-12-07 Edited Resistor, Capacitor, and IC Designators for signal conditioning Subsystem
    Changed all of the Resistors and Capacitors and IC designators staring with PGAs --> Differential Amps in a reading format (changed from left to right, with a few exceptions)
    [Capstone_Signal_Conditioners_Subsystem_Test_Schematic.SchDoc, LTC6362_Schematic.SchDoc, LTC6362_Schematic_2.SchDoc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]
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2022-12-07 Trace Edits on Main PCB Design
    Made a few edits to the traces on the PGA that were causing some problems.
    [LTC6362_Schematic.SchDoc]
2022-12-07 Saved Main PCB File
    Sorry misclicked and saved again. No changes made.
    [UL-SWAP-DAQ-1.PrjPcb]
2022-12-07 Updated PCB with final Resistor and Capacitor changes to signal conditioners
    Accidentally forgot to update my last changes to PCB. It has been updated and is shown on the PCB and Schematic.
    [LTC6362_Schematic.SchDoc]
2022-12-08 Added Nano-D Connector Schematic and Footprint to project
    [Nano_D_Conn_Footprint.SchLib, Nano_D_Conn_Schematic.SchLib]
2022-12-08 test commit for Robert
    test
    [403mainschematic.SchDoc, LMR51420.PcbLib, LMR514205V.SchDoc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]
2022-12-08 adding most Power
    Added all pieces for 3.3 and 5 V power modules. Most of 10.5/-10 module. Added some netnames, pretty sure net names do no conflict with an previously existing
    [403mainschematic.SchDoc, Buck_and_Inverter.SchLib, LMR51420.PcbLib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]
2022-12-08 Updated Nets on Vias for Signal Conditioning connected to power
    Updated vias and fixed the sensor differential connection traces.
    [THS7002CPWP_Schematic.SchDoc, THS7002CPWP_Schematic_2.SchDoc]
2022-12-09 almost all additional componentss for power
    just a few more components left to add and connect up.
    [TPS6513_pcb.PcbLib, TPS6513x.SchDoc]
2022-12-12 all components added to power
    Have not connected the outputs of power to inputs of other subsytems.
2022-12-13 Added in Ground plane, edited traces, and added a few vias
    Made ground plane around the PGAs heatsink, moved some traces around to look nice, and added in a few ground vias for the PGAs
